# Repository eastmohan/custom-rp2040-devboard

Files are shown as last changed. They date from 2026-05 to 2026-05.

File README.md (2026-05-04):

**RP2040 Devboard** </br>
A custom devboard using the RP2040 chip. I made this to get a better understanding of how devboards work. I also wanted to get better at PCB design, which this definitely helped with thanks to the high amount of traces to route in a small footprint.

**BOM** </br>
| Part | Link | Price | 
| --- | --- | --- |
| Custom PCBA | [Link](https://cart.jlcpcb.com/quote/gerberviewThree/?qs=693d5b279bb64dad9bc01a3e98fce2fa_1_0_1_0_0.html) | $44.69 |

</br>

All footprints and symbols used should be in KiCAD by default (KiCAD 10.0 or later).

**Images**







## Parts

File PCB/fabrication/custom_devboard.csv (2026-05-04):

Id | Designator | Footprint | Quantity | Comment | Supplier and ref
1 | C1, C2, C3, C4, C5, C6, C7, C8, C11, C12, C17 | C_0402_1005Metric | 11 | 0.1uF
2 | C9, C10 | C_0402_1005Metric | 2 | 1uF
3 | C13, C14 | C_0603_1608Metric | 2 | 10uF
4 | C15, C16 | C_0402_1005Metric | 2 | 33pF
5 | J1 | USB_C_Receptacle_HRO_TYPE-C-31-M-12 | 1 | USB_C_Receptacle_USB2.0_14P
6 | J2, J3 | PinHeader_1x20_P2.54mm_Vertical | 2 | Conn_01x20
7 | J4 | PinHeader_1x03_P2.54mm_Vertical | 1 | Conn_01x03
8 | R1, R2 | R_0402_1005Metric | 2 | 5.1k
9 | R3, R4 | R_0402_1005Metric | 2 | 27
10 | R5, R7 | R_0402_1005Metric | 2 | 1k
11 | R6 | R_0402_1005Metric | 1 | 10k
12 | SW1 | SW_Push_SPST_NO_Alps_SKRK | 1 | SW_Push
13 | U1 | QFN-56-1EP_7x7mm_P0.4mm_EP3.2x3.2mm | 1 | RP2040
14 | U3 | SOIC-8_5.3x5.3mm_P1.27mm | 1 | W25Q128JVS
15 | U4 | SOT-23 | 1 | MCP1700x-330xxTT
16 | Y1 | Crystal_SMD_3225-4Pin_3.2x2.5mm | 1 | 12MHz

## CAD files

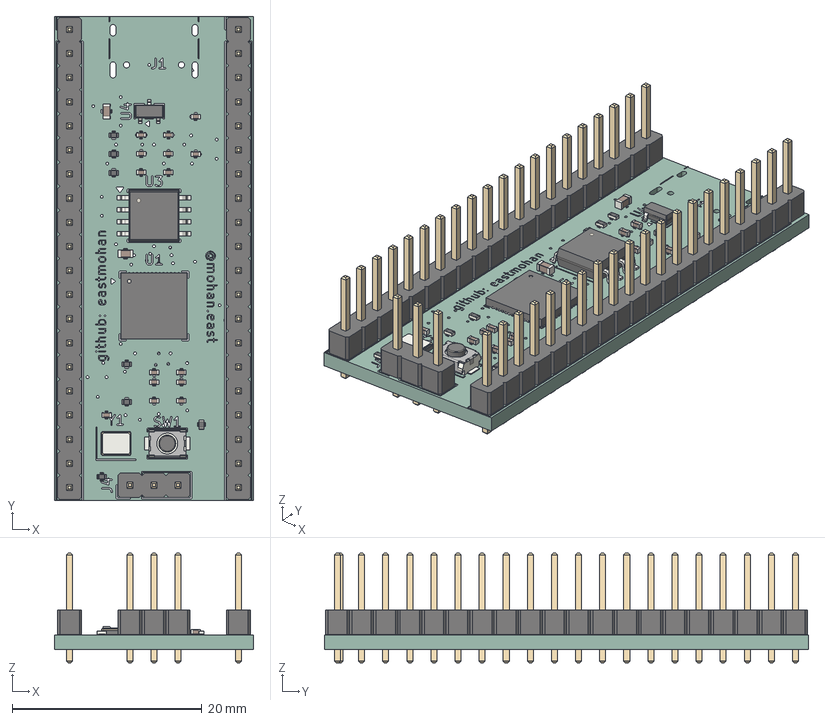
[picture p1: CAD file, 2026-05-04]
CAD/custom_devboard.step
21.0 x 51.0 x 11.5 mm
C_0402_1005Metric x 15
R_0402_1005Metric x 7
SW_Push_SPST_NO_Alps_SKRK
QFN-56-1EP_7x7mm_P0.4mm_EP3.2x3.2mm
Crystal_SMD_3225-4Pin_3.2x2.5mm
PinHeader_1x20_P2.54mm_Vertical x 2
C_0603_1608Metric x 2
PinHeader_1x03_P2.54mm_Vertical
SOT-23
SOIC-8_5.3x5.3mm_P1.27mm
custom_devboard_silkscreen x 2
custom_devboard_PCB

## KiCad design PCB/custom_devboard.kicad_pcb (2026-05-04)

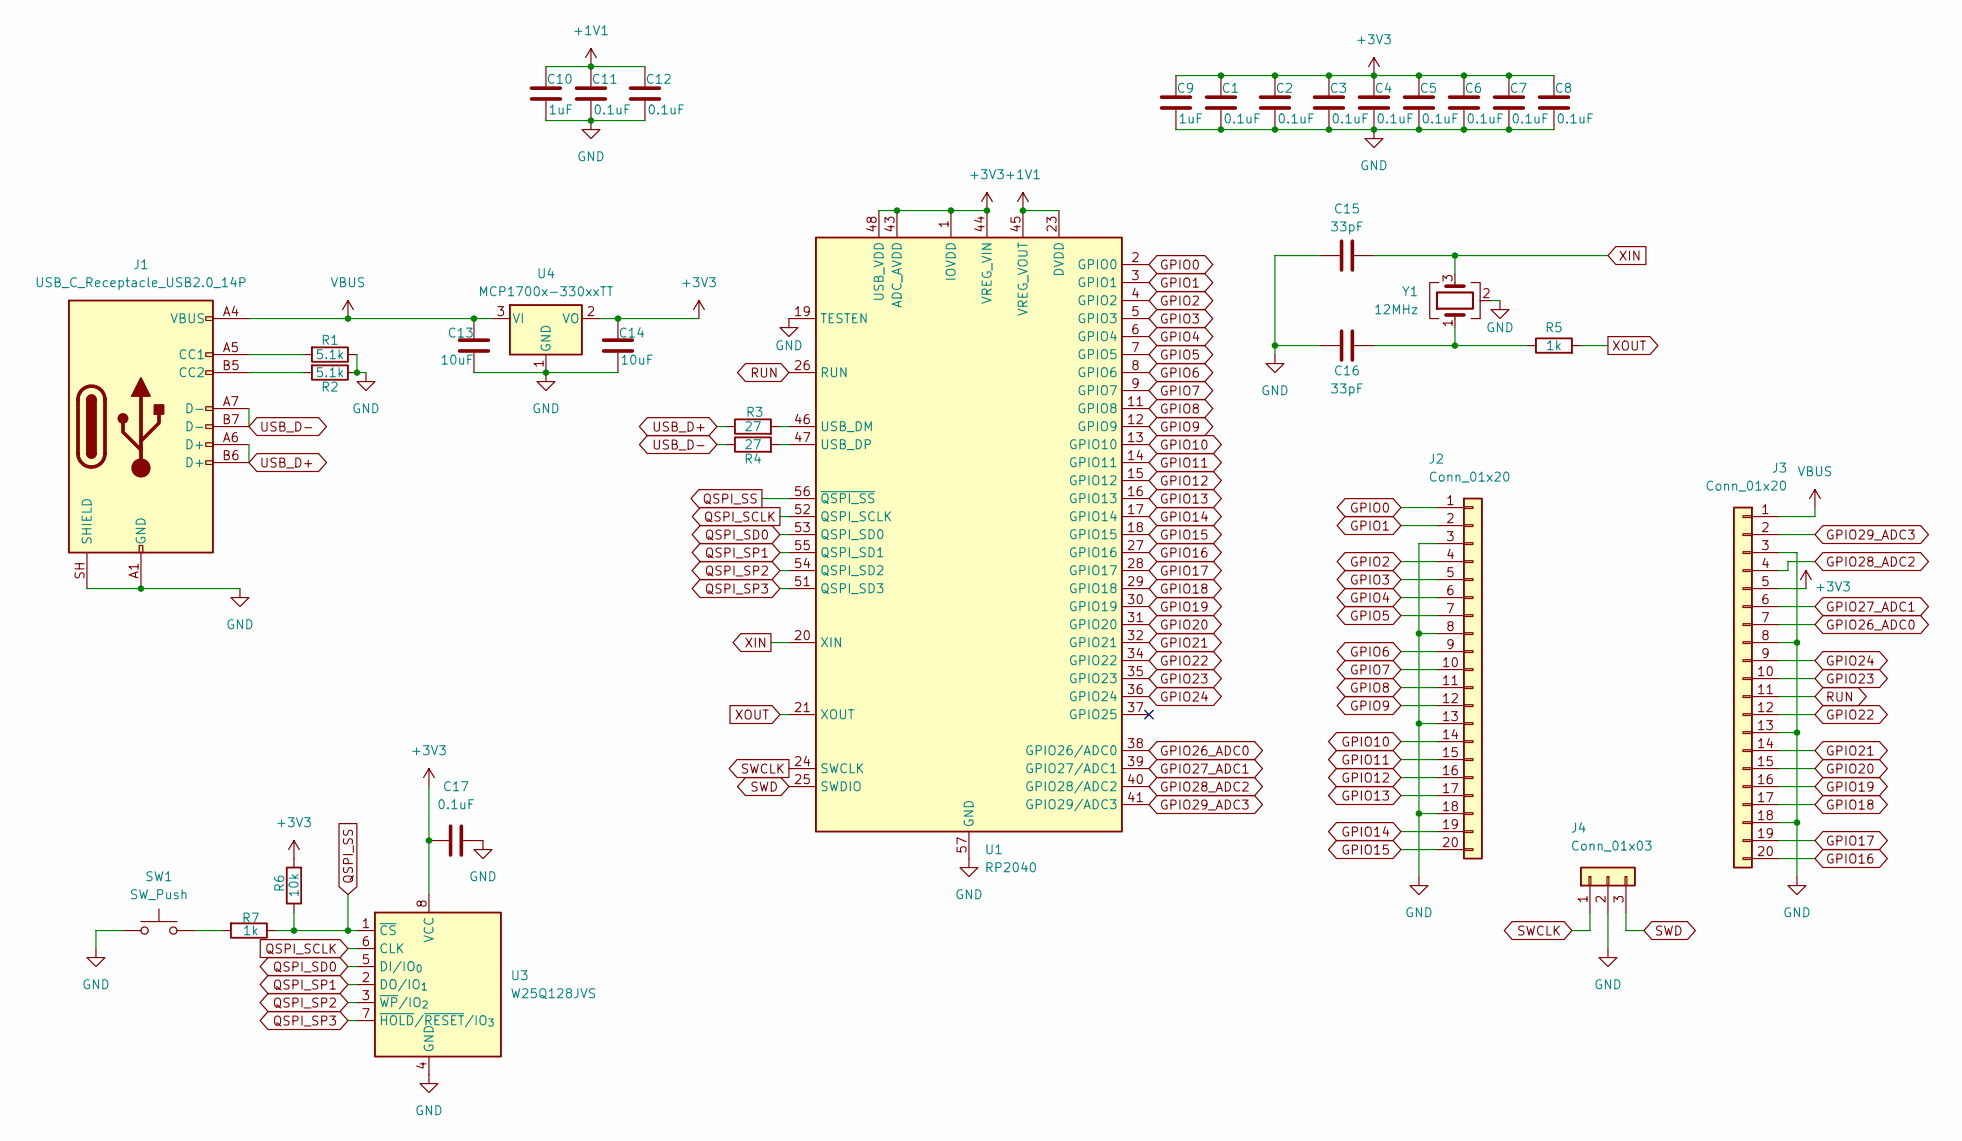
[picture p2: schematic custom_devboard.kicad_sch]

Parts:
C1, C2, C3, C4, C5, C6, C7, C8, C11, C12, C17: 0.1uF; C_0402_1005Metric
C9, C10: 1uF; C_0402_1005Metric
C13, C14: 10uF; C_0603_1608Metric
C15, C16: 33pF; C_0402_1005Metric
J1: USB_C_Receptacle_USB2.0_14P; USB_C_Receptacle_HRO_TYPE-C-31-M-12
J2, J3: Conn_01x20; PinHeader_1x20_P2.54mm_Vertical
J4: Conn_01x03; PinHeader_1x03_P2.54mm_Vertical
R1, R2: 5.1k; R_0402_1005Metric
R3, R4: 27; R_0402_1005Metric
R5, R7: 1k; R_0402_1005Metric
R6: 10k; R_0402_1005Metric
SW1: SW_Push; SW_Push_SPST_NO_Alps_SKRK
U1: RP2040; QFN-56-1EP_7x7mm_P0.4mm_EP3.2x3.2mm
U3: W25Q128JVS; SOIC-8_5.3x5.3mm_P1.27mm
U4: MCP1700x-330xxTT; SOT-23
Y1: 12MHz; Crystal_SMD_3225-4Pin_3.2x2.5mm

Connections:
+1V1: C10.1, C11.1, C12.1, U1.23 (DVDD), U1.45 (VREG_VOUT), U1.50 (DVDD)
+3V3: C1.1, C2.1, C3.1, C4.1, C5.1, C6.1, C7.1, C8.1, C9.1, C14.1, C17.1, J3.5, R6.2, U1.1 (IOVDD), U1.10 (IOVDD), U1.22 (IOVDD), U1.33 (IOVDD), U1.42 (IOVDD), U1.43 (ADC_AVDD), U1.44 (VREG_VIN), U1.48 (USB_VDD), U1.49 (IOVDD), U3.8 (VCC), U4.2 (VO)
GND: C1.2, C2.2, C3.2, C4.2, C5.2, C6.2, C7.2, C8.2, C9.2, C10.2, C11.2, C12.2, C13.2, C14.2, C15.1, C16.1, C17.2, J1.A1 (GND), J1.A12 (GND), J1.B1 (GND), J1.B12 (GND), J1.SH (SHIELD), J2.3, J2.8, J2.13, J2.18, J3.3, J3.8, J3.13, J3.18, J4.2, R1.1, R2.1, SW1.1, U1.19 (TESTEN), U1.57 (GND), U3.4 (GND), U4.1 (GND), Y1.2 (G), Y1.4 (G)
GPIO0: J2.1, U1.2 (GPIO0)
GPIO1: J2.2, U1.3 (GPIO1)
GPIO2: J2.4, U1.4 (GPIO2)
GPIO3: J2.5, U1.5 (GPIO3)
GPIO4: J2.6, U1.6 (GPIO4)
GPIO5: J2.7, U1.7 (GPIO5)
GPIO6: J2.9, U1.8 (GPIO6)
GPIO7: J2.10, U1.9 (GPIO7)
GPIO8: J2.11, U1.11 (GPIO8)
GPIO9: J2.12, U1.12 (GPIO9)
GPIO10: J2.14, U1.13 (GPIO10)
GPIO11: J2.15, U1.14 (GPIO11)
GPIO12: J2.16, U1.15 (GPIO12)
GPIO13: J2.17, U1.16 (GPIO13)
GPIO14: J2.19, U1.17 (GPIO14)
GPIO15: J2.20, U1.18 (GPIO15)
GPIO16: J3.20, U1.27 (GPIO16)
GPIO17: J3.19, U1.28 (GPIO17)
GPIO18: J3.17, U1.29 (GPIO18)
GPIO19: J3.16, U1.30 (GPIO19)
GPIO20: J3.15, U1.31 (GPIO20)
GPIO21: J3.14, U1.32 (GPIO21)
GPIO22: J3.12, U1.34 (GPIO22)
GPIO23: J3.10, U1.35 (GPIO23)
GPIO24: J3.9, U1.36 (GPIO24)
GPIO26_ADC0: J3.7, U1.38 (GPIO26/ADC0)
GPIO27_ADC1: J3.6, U1.39 (GPIO27/ADC1)
GPIO28_ADC2: J3.4, U1.40 (GPIO28/ADC2)
GPIO29_ADC3: J3.2, U1.41 (GPIO29/ADC3)
unnamed: C16.2, R5.1, Y1.1
unnamed: J1.A5 (CC1), R1.2
unnamed: J1.B5 (CC2), R2.2
unnamed: R7.2, SW1.2
unnamed: R3.2, U1.46 (USB_DM)
unnamed: R4.2, U1.47 (USB_DP)
QSPI_SCLK: U1.52 (QSPI_SCLK), U3.6 (CLK)
QSPI_SD0: U1.53 (QSPI_SD0), U3.5 (DI/IO_{0})
QSPI_SP1: U1.55 (QSPI_SD1), U3.2 (DO/IO_{1})
QSPI_SP2: U1.54 (QSPI_SD2), U3.3 (~WP/IO_{2})
QSPI_SP3: U1.51 (QSPI_SD3), U3.7 (~HOLD/~RESET/IO_{3})
QSPI_SS: R6.1, R7.1, U1.56 (~QSPI_SS), U3.1 (~CS)
RUN: J3.11, U1.26 (RUN)
SWCLK: J4.1, U1.24 (SWCLK)
SWD: J4.3, U1.25 (SWDIO)
USB_D+: J1.A6 (D+), J1.B6 (D+), R3.1
USB_D-: J1.A7 (D-), J1.B7 (D-), R4.1
VBUS: C13.1, J1.A4 (VBUS), J1.A9 (VBUS), J1.B4 (VBUS), J1.B9 (VBUS), J3.1, U4.3 (VI)
XIN: C15.2, U1.20 (XIN), Y1.3
XOUT: R5.2, U1.21 (XOUT)

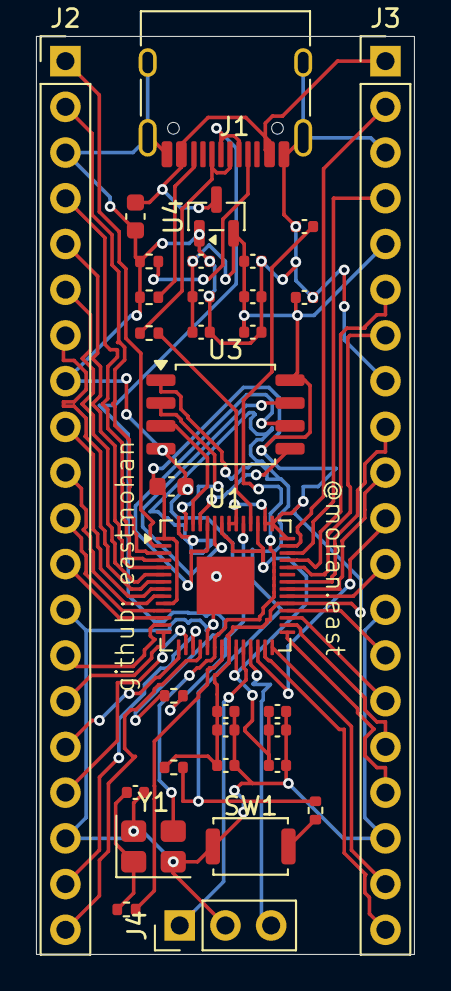
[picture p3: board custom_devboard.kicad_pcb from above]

Board: 2 copper layers, 21.0 x 51.0 mm, 33 parts (0 on the bottom side), 52 nets.

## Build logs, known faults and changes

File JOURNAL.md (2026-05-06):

<!--
  This journal is auto generated by Stasis.
-->

# 5/3/2026 9 PM - JLCPCB Formatting

_Time spent: 0.5833333333333334h_

I set all of the parts in the BOM in JLCPCB so they correspond to the part I need. I also rotated/moved parts as needed on the assembly. Some of the parts it took a few tries to get the right one, such as the crystal oscillator.





# 5/3/2026 9 PM - Made production files

_Time spent: 0.3333333333333333h_

I generated all of the files from KiCAD for production. This took a while because Excel was messing up the formatting of the .csv files so after a few tries I realized I needed to upload it too Google Drive and change it in Google Sheets. I then put it all in a folder and compressed it to PRODUCTION.zip.





# 4/11/2026 1 AM - Edited silkscreen

_Time spent: 0.55h_

I made all of these changes twice and some three times because kicad crashed a few times. I deleted labels for caps and resistors, and tried making an image for silkscreen but the kicad image converter kept failing. Whenever I tried making a rectangle with hatched fill, kicad threw an error and crashed without saving my work. This happened twice. 

This is how my PCB looks now:



 When I order the PCB I think I'll get a color other than green because I feel like it looks better and it costs the same, though it takes a bit longer.





# 4/10/2026 2 AM - Done with footprint

_Time spent: 0.3833333333333334h_

I had only 1 error after routing the remaining trace. Turns out there was one I forgot to route. It took some rearranging but wasn't too hard. Huge thanks to noah.alam77 on slack for finding where I could connect the parts from the previous journal. This is the finished footprint/PCB:








# 4/10/2026 1 AM - Finished most of the footprint

_Time spent: 2.066666666666667h_

This has been really fun and satisfying but also really frustrating. I've had to get creative with how I route some of the traces and had to delete lots of traces and redo them because I couldn't get them to work. I spend probably 45 minutes trying to get the last 7 traces to work, one of which I still can't figure out how to route. This is the footprint as of now, with one trace left to route.

Remaining connection:





# 4/9/2026 2 AM - Started PCB

_Time spent: 0.9166666666666666h_

I started making the actual PCB in KiCAD. I accidentally used the wrong footprint for the 3 pin pinheader (fanpin instead of pin for some reason), so I fixed that.

I want to use the original amount of flash and such thats in the guide so I'm going to try to fit everything in the small size of the board but I'm having trouble already, with only a few traces drawn. I also spend little to no time arranging components, so that might have something to do with it.









# 4/9/2026 1 AM - Finished the schematic

_Time spent: 0.7833333333333333h_

It was pretty easy once I figured out why the 4th pin was hidden and the rest of the schematic was really repetitive with placing all of the global tags. I used the macropad I made and set a macro to generate the tags I wanted from GPIO0 to GPIO25, which saved a lot of time. I'm glad KiCAD has a way to input multiple tags at once because it saved me a ton of time as I could just list the tags all at once.





# 4/8/2026 6 PM - Started the schematic

_Time spent: 1.216666666666667h_

It went pretty smoothly following the guide but there were a few issues. The first thing I noticed was that the symbol for the RP2040 in my version of KiCAD was different from the one on the guide, so I had to be careful the whole time to use the right pins. Second, I couldn't find how to place a global label. After some research, I found out you have to long press the net label button and then you can switch to global. The third issue took like 20 minutes to figure out. I was using the same symbol as the guide for the crystal, but mine only had 3 pins visible, whereas the guide had 4. 

Mine:

Guide:


After some research, I figured it must be hidden. I rand ERC and sure enough, it showed 4 unconnected pins on the crystal symbol.


So, I went in the symbol editor and after some digging I found that it was stacked under pin 2 and marked as hidden. 

I'm leaving it as is but if I have an issue later related to the crystal I think this is why. 

This is what I have so far:









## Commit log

2026-05-04 Added PCB Files
    [custom_devboard-B_Cu.gbr, custom_devboard-B_Mask.gbr, custom_devboard-B_Paste.gbr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]
2026-05-04 Added CAD
    [custom_devboard.step]
